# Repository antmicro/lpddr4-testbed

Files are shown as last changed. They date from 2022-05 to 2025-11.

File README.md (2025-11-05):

LPDDR4 testbed
==============

Copyright (c) 2020-2025 [Antmicro](https://www.antmicro.com)



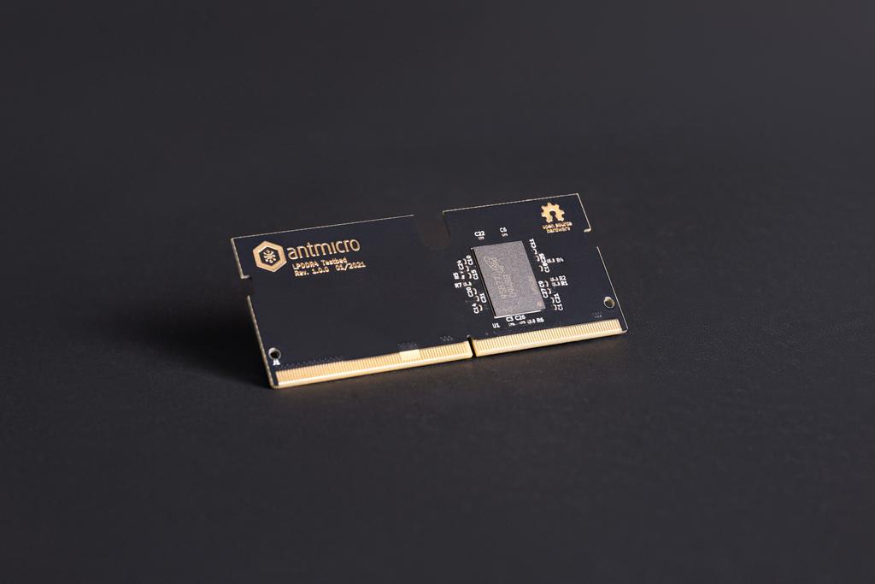
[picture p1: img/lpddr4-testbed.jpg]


Overview
--------

This repository contains open hardware design files for an experimental
test module in a form of SO-DIMM DDR4 module. The module includes a
standard 200-ball WFBGA (10mm × 14.5mm × 0.8mm, Ø0.35 SMD) LPDDR4 RAM
footprint break-routed in the SO-DOMM edge connector. The design files
were prepared in KiCad. Please note that this board is not electrically
compatible with off-the-shelf SO-DIMM DDR4 memory modules. It is
compatible with [this](https://github.com/antmicro/lpddr4-test-board)
LPDDR4 test platform.

Repository structure
--------------------

The main repository directory contains KiCad PCB project files, a
LICENSE and README. The remaining files are stored in the following
directories:

* `img` - contains graphics for this README

### Licensing

This project is published under the [Apache-2.0](LICENSE) license.

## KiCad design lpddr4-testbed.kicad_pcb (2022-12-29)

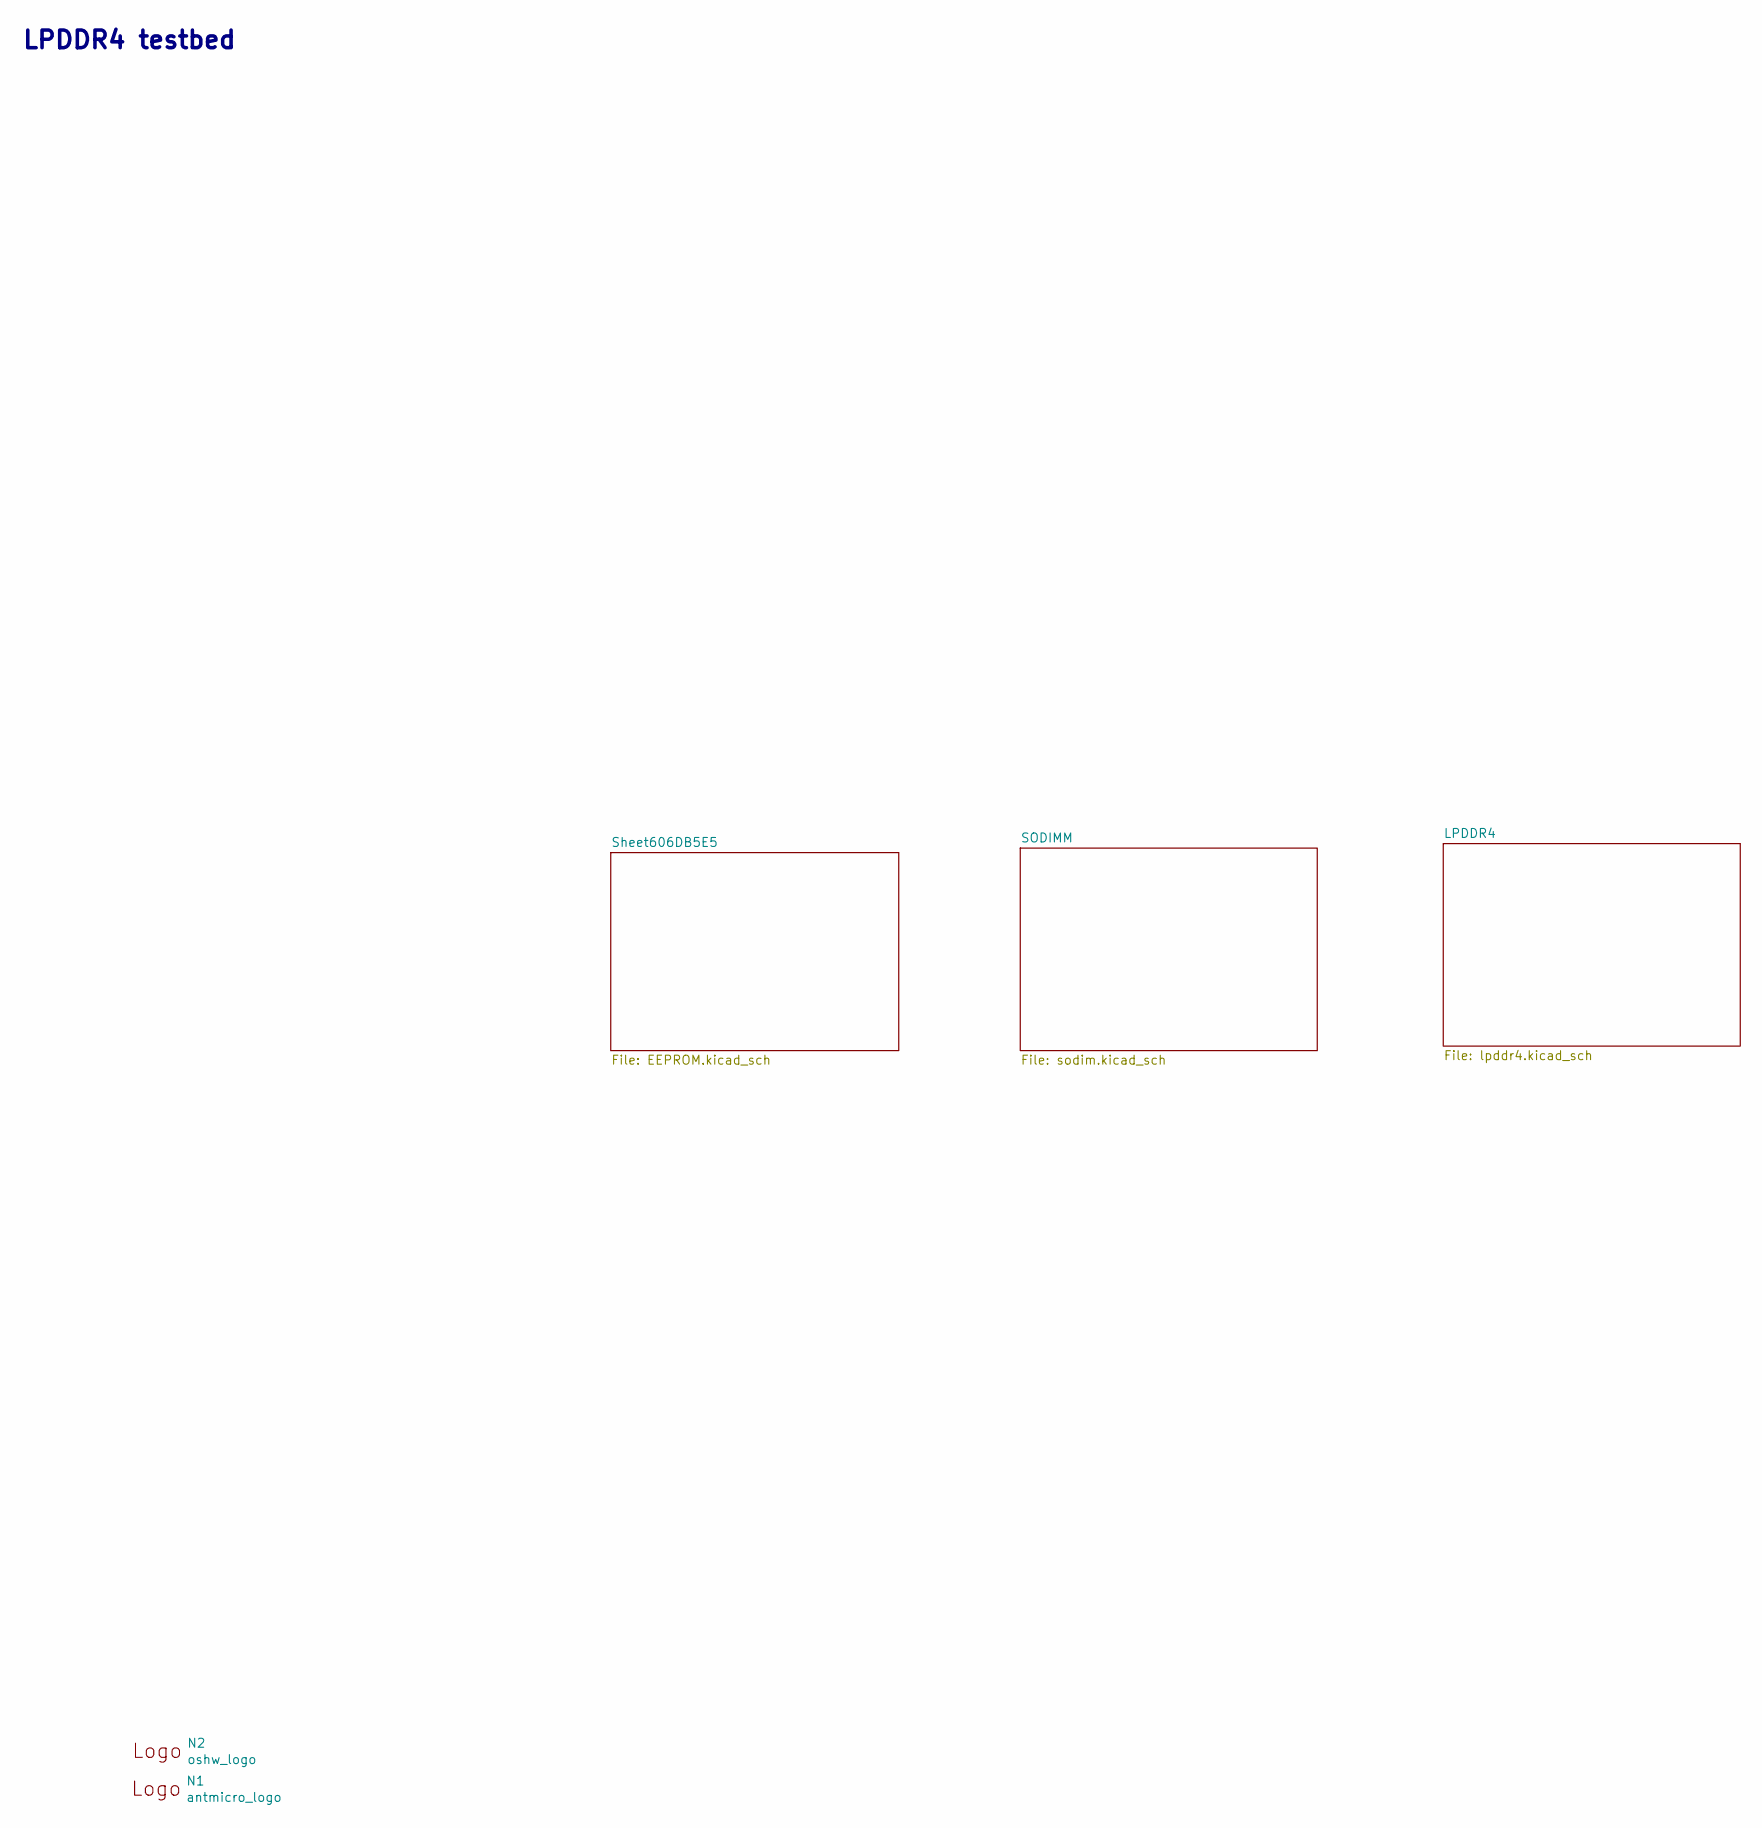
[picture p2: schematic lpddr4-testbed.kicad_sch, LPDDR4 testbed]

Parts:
N1: antmicro_logo; antmicro-logo_scaled_20mm
N2: oshw_logo; oshw-logo

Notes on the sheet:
LPDDR4 testbed

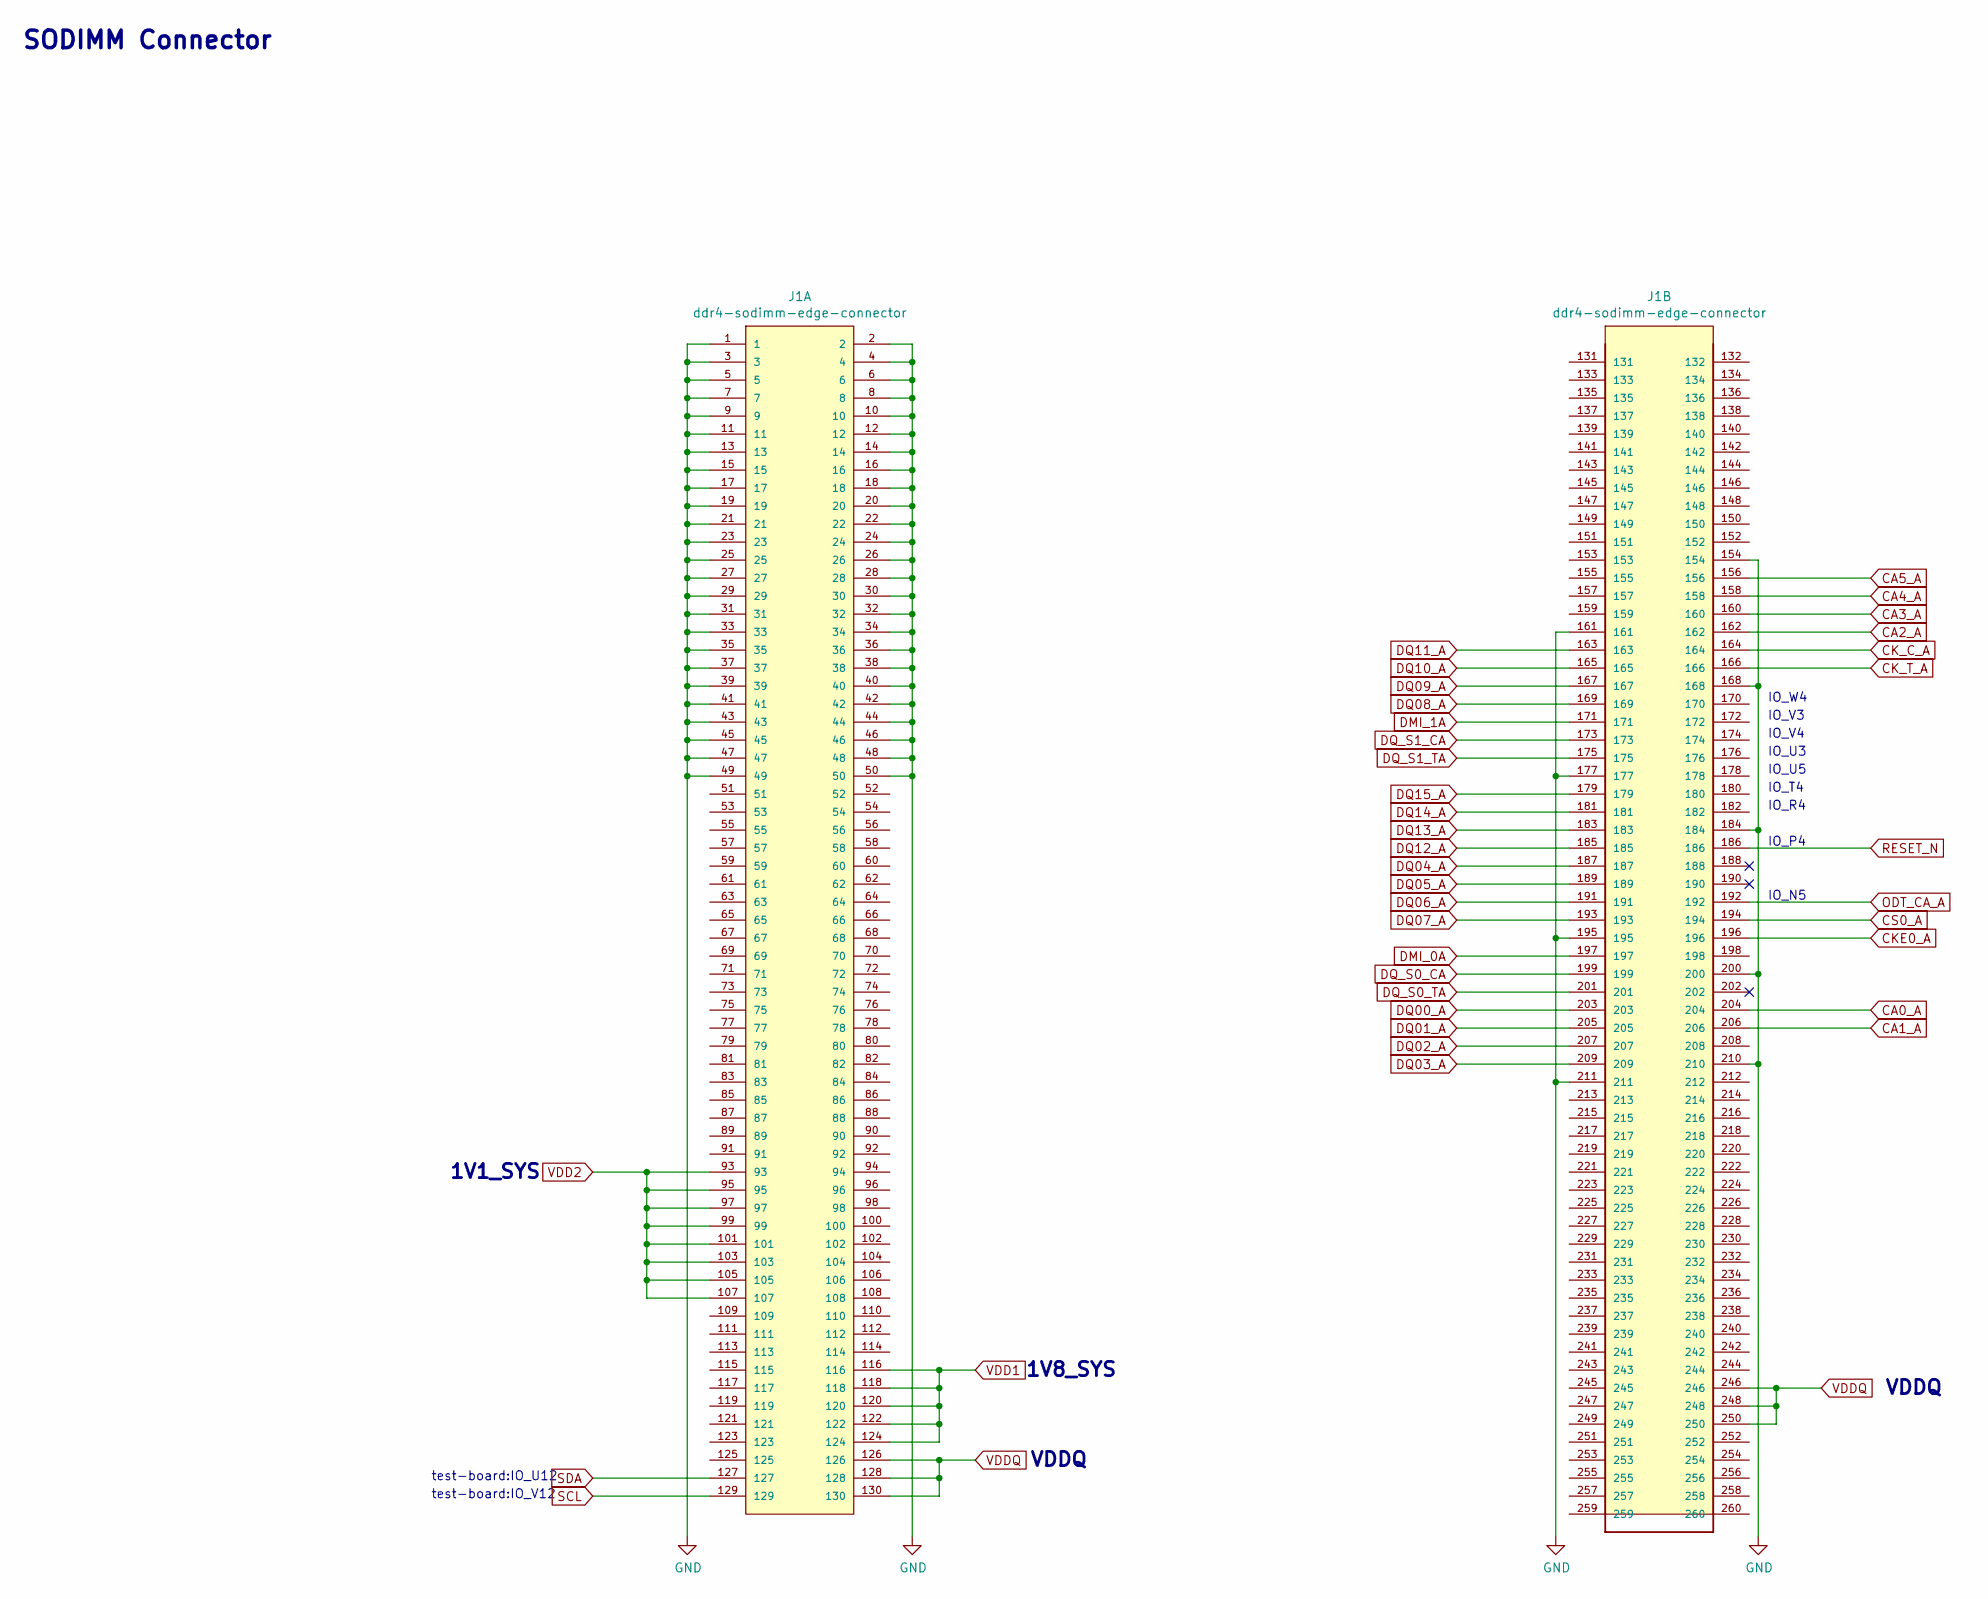
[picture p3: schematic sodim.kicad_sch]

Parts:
J1: ddr4-sodimm-edge-connector; SODIMM_DDR4_EDGE

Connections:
CA0_A: J1.204; also elsewhere on the board
CA1_A: J1.206; also elsewhere on the board
CA2_A: J1.162; also elsewhere on the board
CA3_A: J1.160; also elsewhere on the board
CA4_A: J1.158; also elsewhere on the board
CA5_A: J1.156; also elsewhere on the board
CKE0_A: J1.196; also elsewhere on the board
CK_C_A: J1.164; also elsewhere on the board
CK_T_A: J1.166; also elsewhere on the board
CS0_A: J1.194; also elsewhere on the board
DMI_0A: J1.197; also elsewhere on the board
DMI_1A: J1.171; also elsewhere on the board
DQ00_A: J1.203; also elsewhere on the board
DQ01_A: J1.205; also elsewhere on the board
DQ02_A: J1.207; also elsewhere on the board
DQ03_A: J1.209; also elsewhere on the board
DQ04_A: J1.187; also elsewhere on the board
DQ05_A: J1.189; also elsewhere on the board
DQ06_A: J1.191; also elsewhere on the board
DQ07_A: J1.193; also elsewhere on the board
DQ08_A: J1.169; also elsewhere on the board
DQ09_A: J1.167; also elsewhere on the board
DQ10_A: J1.165; also elsewhere on the board
DQ11_A: J1.163; also elsewhere on the board
DQ12_A: J1.185; also elsewhere on the board
DQ13_A: J1.183; also elsewhere on the board
DQ14_A: J1.181; also elsewhere on the board
DQ15_A: J1.179; also elsewhere on the board
DQ_S0_CA: J1.199; also elsewhere on the board
DQ_S0_TA: J1.201; also elsewhere on the board
DQ_S1_CA: J1.173; also elsewhere on the board
DQ_S1_TA: J1.175; also elsewhere on the board
GND: J1.1, J1.2, J1.3, J1.4, J1.5, J1.6, J1.7, J1.8, J1.9, J1.10, J1.11, J1.12, J1.13, J1.14, J1.15, J1.16, J1.17, J1.18, J1.19, J1.20, J1.21, J1.22, J1.23, J1.24, J1.25, J1.26, J1.27, J1.28, J1.29, J1.30, J1.31, J1.32, J1.33, J1.34, J1.35, J1.36, J1.37, J1.38, J1.39, J1.40, J1.41, J1.42, J1.43, J1.44, J1.45, J1.46, J1.47, J1.48, J1.49, J1.50, J1.154, J1.161, J1.168, J1.177, J1.184, J1.195, J1.200, J1.210, J1.211; also elsewhere on the board
ODT_CA_A: J1.192; also elsewhere on the board
RESET_N: J1.186; also elsewhere on the board
SCL: J1.129; also elsewhere on the board
SDA: J1.127; also elsewhere on the board
VDD1: J1.116, J1.118, J1.120, J1.122, J1.124; also elsewhere on the board
VDD2: J1.93, J1.95, J1.97, J1.99, J1.101, J1.103, J1.105, J1.107; also elsewhere on the board
VDDQ: J1.126, J1.128, J1.130, J1.246, J1.248, J1.250; also elsewhere on the board

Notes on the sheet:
IO_W4
IO_N5
IO_U5
IO_T4
test-board:IO_U12
VDDQ
IO_U3
IO_V4
IO_P4
test-board:IO_V12
SODIMM Connector
IO_V3
IO_R4
1V8_SYS
1V1_SYS

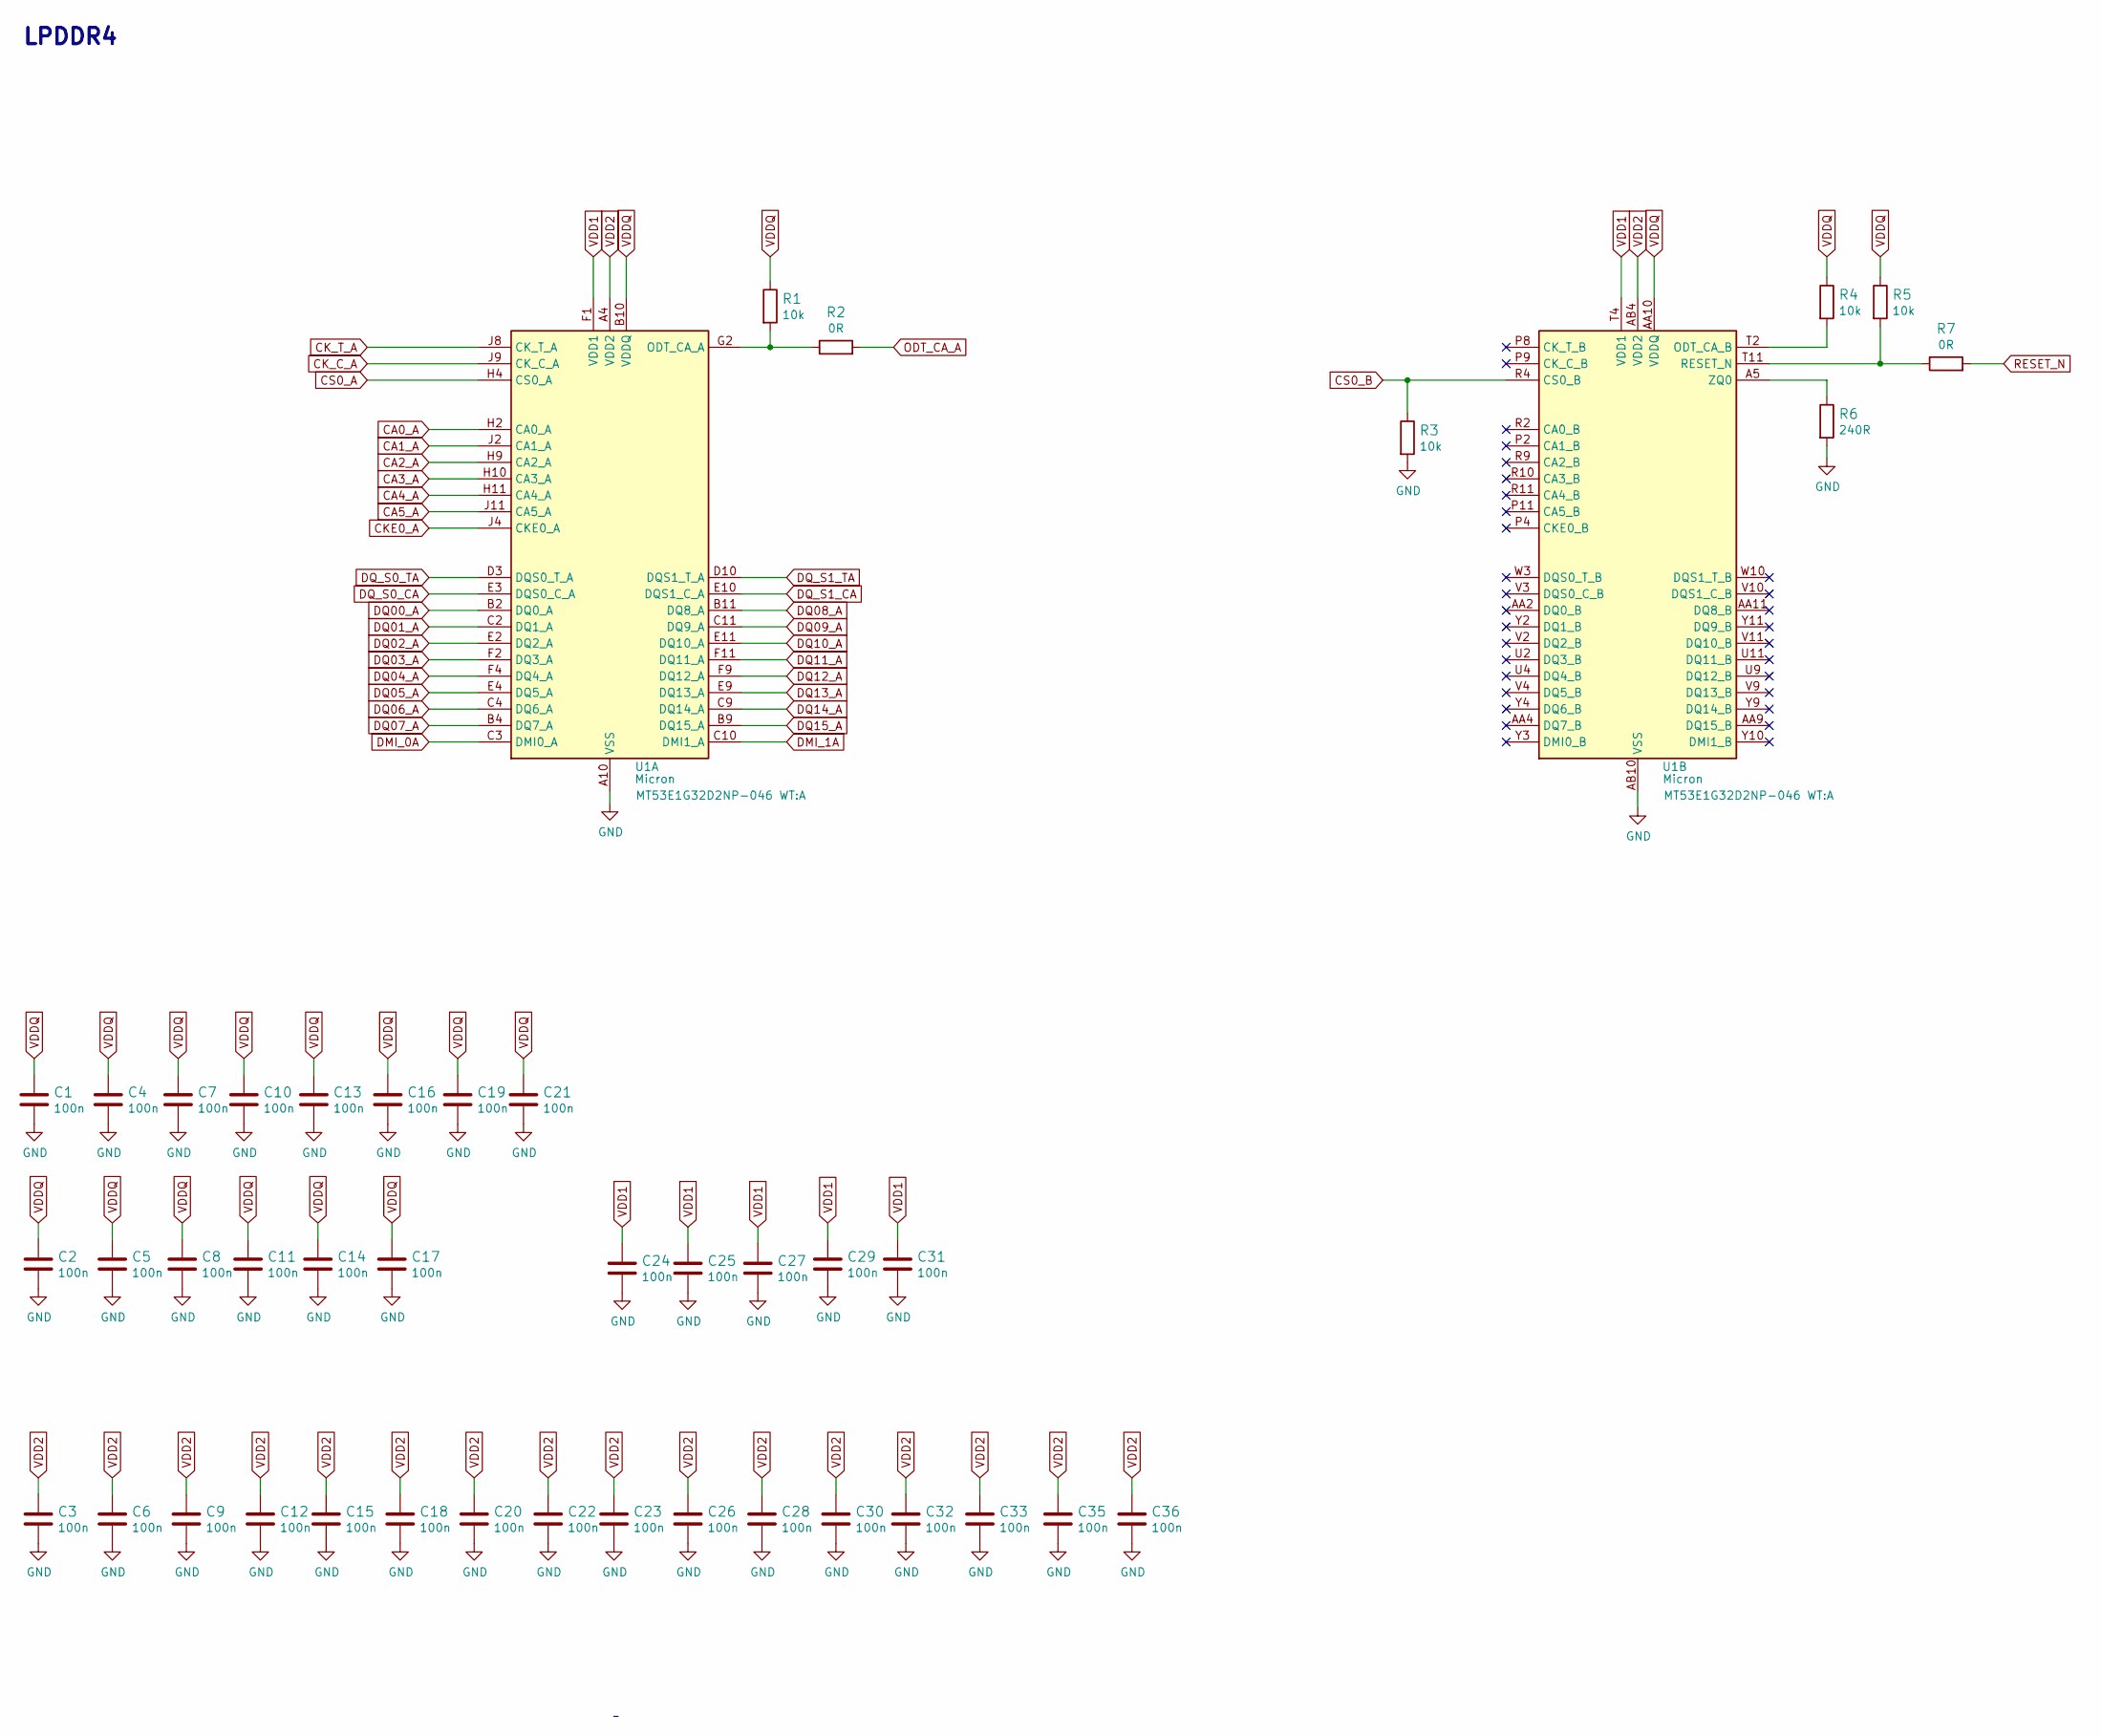
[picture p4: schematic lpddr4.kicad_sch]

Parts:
C1, C2, C3, C4, C5, C6, C7, C8, C9, C10, C11, C12, C13, C14, C15, C16, C17, C18, C19, C20, C21, C22, C23, C24, C25, C26, C27, C28, C29, C30, C31, C32, C33, C35, C36: C_100n_0201; 0201-res; MPN CC0201KRX6S5BB104
R1, R3, R4, R5: R_10k_0402; 0402-res; MPN CRCW040210K0FKEDHP
R2, R7: R_0R_0402; 0402-res; MPN ERJ2GE0R00X
R6: R_240R_0402; 0402-res; MPN ERJ2GEJ241X
U1: MT53E1G32D2NP-046; BGA-200_10.0x14.5mm_Layout12x22_P0.80x0.65mm; MPN MT53E1G32D2NP-046 WT:A

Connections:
CA0_A: U1.H2 (CA0_A); also elsewhere on the board
CA1_A: U1.J2 (CA1_A); also elsewhere on the board
CA2_A: U1.H9 (CA2_A); also elsewhere on the board
CA3_A: U1.H10 (CA3_A); also elsewhere on the board
CA4_A: U1.H11 (CA4_A); also elsewhere on the board
CA5_A: U1.J11 (CA5_A); also elsewhere on the board
CKE0_A: U1.J4 (CKE0_A); also elsewhere on the board
CK_C_A: U1.J9 (CK_C_A); also elsewhere on the board
CK_T_A: U1.J8 (CK_T_A); also elsewhere on the board
CS0_A: U1.H4 (CS0_A); also elsewhere on the board
CS0_B: R3.1, U1.R4 (CS0_B)
DMI_0A: U1.C3 (DMI0_A); also elsewhere on the board
DMI_1A: U1.C10 (DMI1_A); also elsewhere on the board
DQ00_A: U1.B2 (DQ0_A); also elsewhere on the board
DQ01_A: U1.C2 (DQ1_A); also elsewhere on the board
DQ02_A: U1.E2 (DQ2_A); also elsewhere on the board
DQ03_A: U1.F2 (DQ3_A); also elsewhere on the board
DQ04_A: U1.F4 (DQ4_A); also elsewhere on the board
DQ05_A: U1.E4 (DQ5_A); also elsewhere on the board
DQ06_A: U1.C4 (DQ6_A); also elsewhere on the board
DQ07_A: U1.B4 (DQ7_A); also elsewhere on the board
DQ08_A: U1.B11 (DQ8_A); also elsewhere on the board
DQ09_A: U1.C11 (DQ9_A); also elsewhere on the board
DQ10_A: U1.E11 (DQ10_A); also elsewhere on the board
DQ11_A: U1.F11 (DQ11_A); also elsewhere on the board
DQ12_A: U1.F9 (DQ12_A); also elsewhere on the board
DQ13_A: U1.E9 (DQ13_A); also elsewhere on the board
DQ14_A: U1.C9 (DQ14_A); also elsewhere on the board
DQ15_A: U1.B9 (DQ15_A); also elsewhere on the board
DQ_S0_CA: U1.E3 (DQS0_C_A); also elsewhere on the board
DQ_S0_TA: U1.D3 (DQS0_T_A); also elsewhere on the board
DQ_S1_CA: U1.E10 (DQS1_C_A); also elsewhere on the board
DQ_S1_TA: U1.D10 (DQS1_T_A); also elsewhere on the board
GND: C1.2, C2.2, C3.2, C4.2, C5.2, C6.2, C7.2, C8.2, C9.2, C10.2, C11.2, C12.2, C13.2, C14.2, C15.2, C16.2, C17.2, C18.2, C19.2, C20.2, C21.2, C22.2, C23.2, C24.2, C25.2, C26.2, C27.2, C28.2, C29.2, C30.2, C31.2, C32.2, C33.2, C35.2, C36.2, R3.2, R6.2, U1.A3 (VSS), U1.A10 (VSS), U1.AB3 (VSS), U1.AB5 (VSS), U1.AB8 (VSS), U1.AB10 (VSS), U1.C1 (VSS), U1.C5 (VSS), U1.C8 (VSS), U1.C12 (VSS), U1.D2 (VSS), U1.D4 (VSS), U1.D9 (VSS), U1.D11 (VSS), U1.E1 (VSS), U1.E5 (VSS), U1.E8 (VSS), U1.E12 (VSS), U1.G1 (VSS), U1.G3 (VSS), U1.G5 (VSS), U1.G8 (VSS), U1.G10 (VSS), U1.G12 (VSS), U1.J1 (VSS), U1.J3 (VSS), U1.J10 (VSS), U1.J12 (VSS), U1.K2 (VSS), U1.K4 (VSS), U1.K9 (VSS), U1.K11 (VSS), U1.N2 (VSS), U1.N4 (VSS), U1.N9 (VSS), U1.N11 (VSS), U1.P1 (VSS), U1.P3 (VSS), U1.P10 (VSS), U1.P12 (VSS), U1.T1 (VSS), U1.T3 (VSS), U1.T5 (VSS), U1.T8 (VSS), U1.T10 (VSS), U1.T12 (VSS), U1.V1 (VSS), U1.V5 (VSS), U1.V8 (VSS), U1.V12 (VSS), U1.W2 (VSS), U1.W4 (VSS), U1.W9 (VSS), U1.W11 (VSS), U1.Y1 (VSS), U1.Y5 (VSS), U1.Y8 (VSS), U1.Y12 (VSS); also elsewhere on the board
unnamed: R1.2, R2.1, U1.G2 (ODT_CA_A)
unnamed: R4.2, U1.T2 (ODT_CA_B)
unnamed: R5.2, R7.1, U1.T11 (RESET_N)
unnamed: R6.1, U1.A5 (ZQ0)
ODT_CA_A: R2.2; also elsewhere on the board
RESET_N: R7.2; also elsewhere on the board
VDD1: C24.1, C25.1, C27.1, C29.1, C31.1, U1.F1 (VDD1), U1.F12 (VDD1), U1.G4 (VDD1), U1.G9 (VDD1), U1.T4 (VDD1), U1.T9 (VDD1), U1.U1 (VDD1), U1.U12 (VDD1); also elsewhere on the board
VDD2: C3.1, C6.1, C9.1, C12.1, C15.1, C18.1, C20.1, C22.1, C23.1, C26.1, C28.1, C30.1, C32.1, C33.1, C35.1, C36.1, U1.A4 (VDD2), U1.A9 (VDD2), U1.AB4 (VDD2), U1.AB9 (VDD2), U1.F5 (VDD2), U1.F8 (VDD2), U1.H1 (VDD2), U1.H5 (VDD2), U1.H8 (VDD2), U1.H12 (VDD2), U1.K1 (VDD2), U1.K3 (VDD2), U1.K10 (VDD2), U1.K12 (VDD2), U1.N1 (VDD2), U1.N3 (VDD2), U1.N10 (VDD2), U1.N12 (VDD2), U1.R1 (VDD2), U1.R5 (VDD2), U1.R8 (VDD2), U1.R12 (VDD2), U1.U5 (VDD2), U1.U8 (VDD2); also elsewhere on the board
VDDQ: C1.1, C2.1, C4.1, C5.1, C7.1, C8.1, C10.1, C11.1, C13.1, C14.1, C16.1, C17.1, C19.1, C21.1, R1.1, R4.1, R5.1, U1.AA3 (VDDQ), U1.AA5 (VDDQ), U1.AA8 (VDDQ), U1.AA10 (VDDQ), U1.B3 (VDDQ), U1.B5 (VDDQ), U1.B8 (VDDQ), U1.B10 (VDDQ), U1.D1 (VDDQ), U1.D5 (VDDQ), U1.D8 (VDDQ), U1.D12 (VDDQ), U1.F3 (VDDQ), U1.F10 (VDDQ), U1.U3 (VDDQ), U1.U10 (VDDQ), U1.W1 (VDDQ), U1.W5 (VDDQ), U1.W8 (VDDQ), U1.W12 (VDDQ); also elsewhere on the board

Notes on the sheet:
LPDDR4

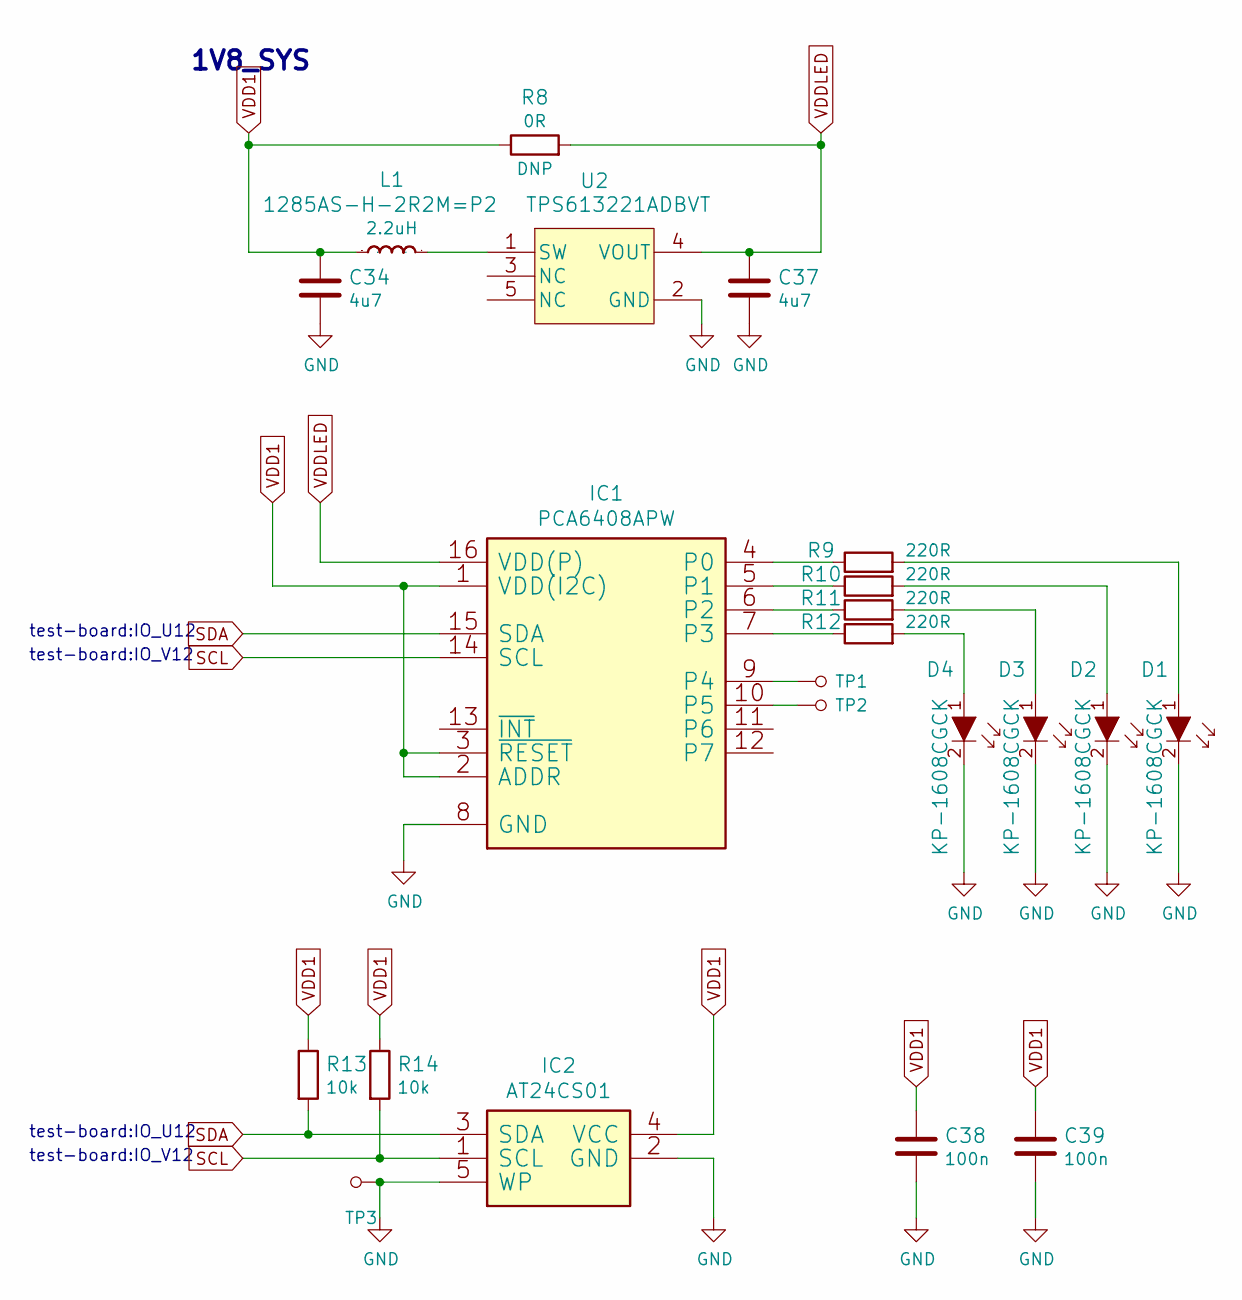
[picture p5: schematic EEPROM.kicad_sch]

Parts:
C34, C37: C_4u7_0402; 0402-cap; MPN GRM155R61A475MEAAD
C38, C39: C_100n_0402; 0402-cap; MPN 0402X104K6R3CT
D1, D2, D3, D4: KP-1608CGCK; LED_0603; MPN KP-1608CGCK
IC1: PCA6408APW; TSSOP-16; MPN PCA6408APW
IC2: AT24CS01; SOT-23-5; MPN AT24CS01-ST
L1: 1285AS-H-2R2M=P2; 0805-res; MPN 1285AS-H-2R2M=P2
R8: R_0R_0402; 0402-res; MPN ERJ2GE0R00X
R9, R10, R11, R12: R_220R_0402; 0402-res; MPN ERJ2GEJ221X
R13, R14: R_10k_0402; 0402-res; MPN CRCW040210K0FKEDHP
TP1, TP2, TP3: TP_SMD1MM; Testpoint_smd_1mm
U2: TPS613221ADBVT; SOT-23-5; MPN TPS613221ADBVT

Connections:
GND: C34.2, C37.2, C38.2, C39.2, D1.2, D2.2, D3.2, D4.2, IC1.8 (GND), IC2.2 (GND), IC2.5 (WP), TP3.1, U2.2 (GND); also elsewhere on the board
unnamed: D1.1, R9.2
unnamed: D2.1, R10.2
unnamed: D3.1, R11.2
unnamed: D4.1, R12.2
unnamed: IC1.4 (P0), R9.1
unnamed: IC1.5 (P1), R10.1
unnamed: IC1.6 (P2), R11.1
unnamed: IC1.7 (P3), R12.1
unnamed: IC1.9 (P4), TP1.1
unnamed: IC1.10 (P5), TP2.1
unnamed: L1.2, U2.1 (SW)
SCL: IC1.14 (SCL), IC2.1 (SCL), R14.2; also elsewhere on the board
SDA: IC1.15 (SDA), IC2.3 (SDA), R13.2; also elsewhere on the board
VDD1: C34.1, C38.1, C39.1, IC1.1 (VDD(I2C)), IC1.2 (ADDR), IC1.3 (~RESET), IC2.4 (VCC), L1.1, R8.1, R13.1, R14.1; also elsewhere on the board
VDDLED: C37.1, IC1.16 (VDD(P)), R8.2, U2.4 (VOUT)

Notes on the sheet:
test-board:IO_V12
test-board:IO_U12
1V8_SYS

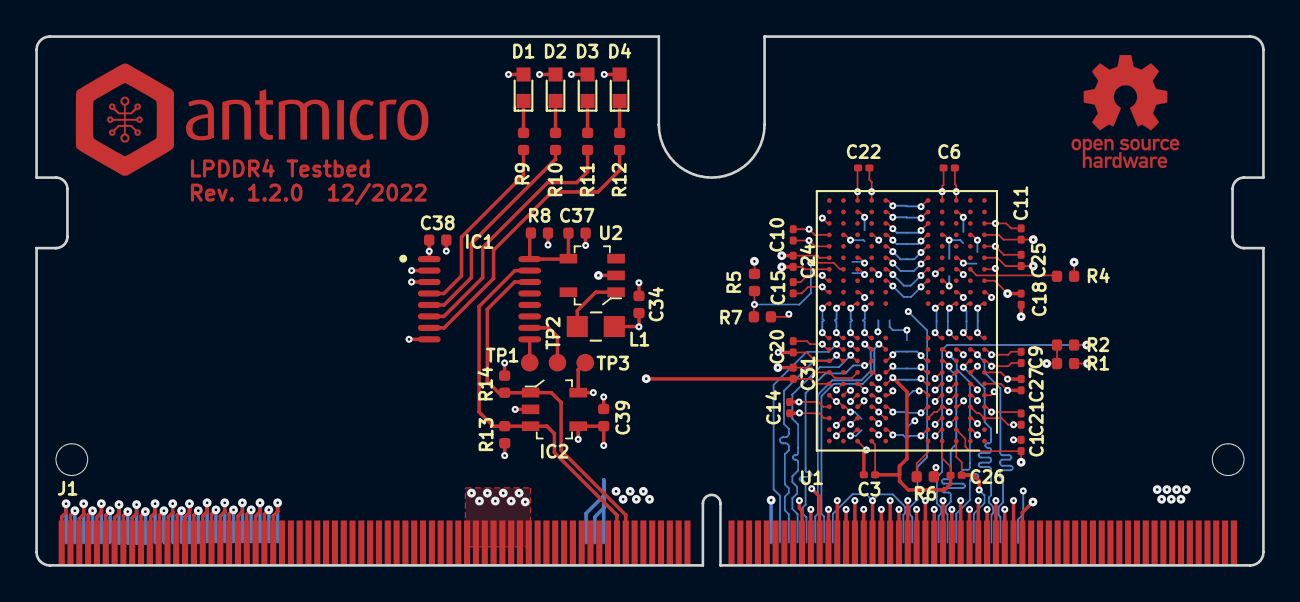
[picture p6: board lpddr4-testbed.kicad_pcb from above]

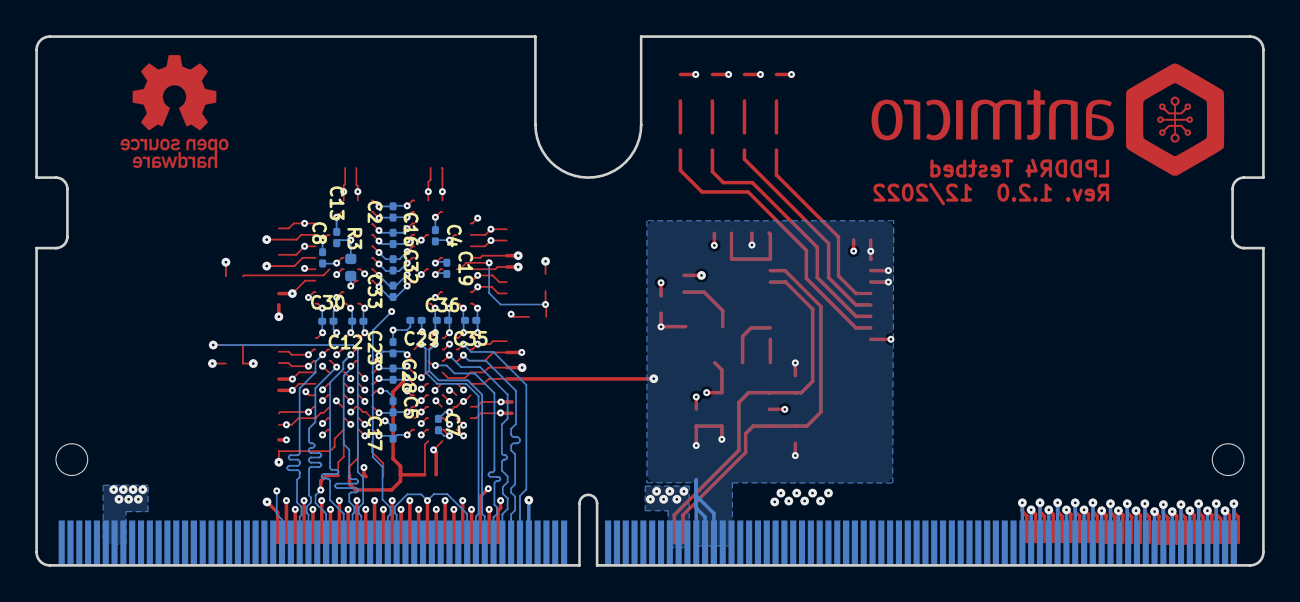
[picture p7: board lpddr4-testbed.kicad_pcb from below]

Board: 6 copper layers, 69.6 x 30.0 mm, 68 parts (19 on the bottom side), 57 nets.

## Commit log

2020-11-02 Add schamatic sheet
    [ddr-testbed.sch]
2020-12-10 Add basic PCB outline
    [ddr-testbed.kicad_pcb]
2020-12-10 Fix outline
    [ddr-testbed.kicad_pcb]
2020-12-10 Add double die configuration
    [ddr-testbed.sch]
2020-12-10 Add data resistors sheet
    [data_resistors.sch, ddr-testbed.sch]
2020-12-10 Fix outline_v2
    [ddr-testbed.kicad_pcb]
2020-12-10 Add power filtering sheet
    [ddr-testbed.sch, power_filtering.sch]
2020-12-10 Change labels to global
    [data_resistors.sch, ddr-testbed.sch]
2020-12-10 Add changes refering to Xilinx documentation
    [ddr-testbed.sch]
2020-12-10 Add changes in pull ups and add missing components
    [ddr-testbed.sch]
2020-12-10 Add changes around CKE pins and some notes
    [ddr-testbed.sch]
2020-12-10 Remove data resistors sheet and add notes
    [data_resistors.sch, ddr-testbed.sch, power_filtering.sch]
2020-12-10 Add initial component placement
    [ddr-testbed.kicad_pcb]
2020-12-10 Add LPDDR4 Fanout and pinout tabele
    [ddr-testbed.kicad_pcb]
2020-12-10 Redesign power supply and filtering WIP
    [ddr-testbed.sch, power_filtering.sch]
2020-12-10 Replace capacitors and place them on PCB
    [ddr-testbed.kicad_pcb, ddr-testbed.sch]
2020-12-10 Preliminary LPDDR4 escape layout
    [ddr-testbed.kicad_pcb, ddr-testbed.sch]
2020-12-10 LPDDR4 escape done, replaced DDR3 edge connector (requires connecting)
    [ddr-testbed.kicad_pcb, ddr-testbed.sch]
2020-12-10 Updated LPDDR4 connection on edge connector (supplies to be added)
    [ddr-testbed.kicad_pcb, ddr-testbed.sch]
2020-12-10 Passive components update, edge connector routing wip
    [ddr-testbed.kicad_pcb, ddr-testbed.sch]
2020-12-10 Added edge connector escape
    [ddr-testbed.kicad_pcb]
2020-12-10 Routing of all high speed DDR signals done
    [ddr-testbed.kicad_pcb, ddr-testbed.sch]
2020-12-10 Connect power supply to SO-DIMM connector
    [ddr-testbed.sch]
2020-12-10 Update file structure
    [ddr-testbed.kicad_pcb, ddr-testbed.sch, lpddr4-testbed.kicad_pcb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]
2020-12-10 Temporarily move filtering caps
    [lpddr4-testbed.kicad_pcb]
2020-12-10 Introduce schematic sheets
    [filtering.sch, lpddr4-testbed.sch, lpddr4.sch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]
2020-12-10 Update edge connector
    [lpddr4-testbed.kicad_pcb, sodim.sch]
2020-12-10 Connect power supplies and CHANNEL A signals to edge connector
    [lpddr4-testbed.kicad_pcb, lpddr4.sch, sodim.sch]
2020-12-10 Connect signals to DDR CHANNEL A
    [lpddr4.sch]
2020-12-10 Update board setup for 6L
    [lpddr4-testbed.kicad_pcb]
2020-12-10 Reverse connections of DQ4_A ... DQ0_A
    [lpddr4-testbed.kicad_pcb, sodim.sch]
2020-12-10 Connect CA and DQ signals
    [lpddr4-testbed.kicad_pcb]
2020-12-10 Add tune DQ length
    [lpddr4-testbed.kicad_pcb]
2020-12-10 Equalize CA lanes
    [lpddr4-testbed.kicad_pcb]
2020-12-10 Add vias for power distribution
    [lpddr4-testbed.kicad_pcb]
2020-12-13 Remove obsolete RC components around CK and CE signals
    [lpddr4.sch]
2020-12-13 Cleanup, add TODOs
    [lpddr4.sch]
2020-12-14 Add filtering caps to VDDQ
    [lpddr4-testbed.kicad_pcb, lpddr4.sch, sodimm.sch]
2020-12-14 Add Filtering to VCC1
    [lpddr4-testbed.kicad_pcb, lpddr4.sch]
2020-12-14 Add filtering to VDD1
    [lpddr4-testbed.kicad_pcb, lpddr4.sch]
2020-12-14 Route power planes
    [lpddr4-testbed.kicad_pcb]
2020-12-14 Fully routed, DRC clean
    [lpddr4-testbed.kicad_pcb, lpddr4-testbed.sch, lpddr4.sch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]
2021-01-13 Reconnect RESET_N and ODT_CA to IO_P4 and IO_N5
    [lpddr4-testbed.kicad_pcb, sodim.sch]
2021-01-13 Remove note
    [lpddr4.sch]
2021-01-13 Update references
    [lpddr4-testbed.kicad_pcb]
2021-01-13 Add OSHW logotype
    [lpddr4-testbed.kicad_pcb, lpddr4.sch]
2021-01-13 Optimize pairs of buried vias
    [lpddr4-testbed.kicad_pcb, lpddr4-testbed.sch, lpddr4.sch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]
2021-01-13 Update local libs, resolve DRC
    [lpddr4-testbed.kicad_pcb, lpddr4-testbed.sch, lpddr4.sch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]
2021-01-13 Remove redundant sheet
    [filtering.sch]
2021-04-01 Update DRAM MPN
    [lpddr4-testbed-BOM-by-layer.csv, lpddr4-testbed-BOM-populated.csv, lpddr4-testbed.kicad_pcb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]
2021-04-02 Added sheet for EEPROM/LEDs
    [EEPROM.sch, lpddr4-testbed.sch, lpddr4.sch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]
2021-04-07 Added EEPROM and LED circuits to schematic
    [EEPROM.sch]
2021-04-07 Component placement for EEPROM/LEDs
    [EEPROM.sch, lpddr4-testbed.kicad_pcb]
2021-04-22 Changed DDR type to MT53E1G32D2NP-046 WT:A
    [lpddr4-testbed.kicad_pcb, lpddr4.sch]
2021-04-22 Add eeprom routing
    [lpddr4-testbed.kicad_pcb]
2021-04-22 Update schematics
2021-05-06 Bump revision to 1.1.0
    [EEPROM.sch, lpddr4-testbed.sch, lpddr4.sch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]
2021-05-20 Bumped rev on PCB
    [lpddr4-testbed.kicad_pcb]
2021-07-02 Replace broken component -PCA6408APW
    [EEPROM.sch, lpddr4-testbed.kicad_pcb, lpddr4.sch]
2022-12-28 Migrate to KiCad 6
    [EEPROM.kicad_sch, EEPROM.sch, lpddr4-testbed.kicad_pcb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]
2022-12-28 Clean DRC
    [lpddr4-testbed.kicad_pcb]
2022-12-28 Replace burried vias with regular vias
    [lpddr4-testbed.kicad_pcb]
2022-12-29 Fix net names
    [EEPROM.kicad_sch, lpddr4-testbed.kicad_pcb, lpddr4-testbed.kicad_sch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]
2022-12-29 Length matching
    [lpddr4-testbed.kicad_pcb]
2022-12-29 Bump revision to 1.2.0
    [EEPROM.kicad_sch, lpddr4-testbed.kicad_pcb, lpddr4-testbed.kicad_sch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]
2022-12-30 Update signage
    [EEPROM.kicad_sch, lpddr4-testbed-BOM-by-layer.csv, lpddr4-testbed-BOM-populated.csv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]
2022-12-30 Update schematic
2023-05-30 [#45231] globlib
    [EEPROM.kicad_sch, lpddr4-testbed.kicad_sch, lpddr4.kicad_sch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]
2023-05-30 Fix missing global links (wip), designators fixed
    [EEPROM.kicad_sch, lpddr4-testbed.kicad_sch, lpddr4.kicad_sch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]
2023-05-31 Fix missing global links
    [EEPROM.kicad_sch, lpddr4-testbed.kicad_sch]
2023-10-13 Introduce component standardization
    [EEPROM.kicad_sch, lpddr4-testbed.kicad_sch, lpddr4.kicad_sch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]
2023-10-16 Add OHP assets, stop ignoring csv
    [stackup.csv]
2024-03-25 [#56947] Correct component references
    [EEPROM.kicad_sch, lpddr4-testbed.kicad_sch, lpddr4.kicad_sch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]
2024-03-26 [#56947] Fix missing highlights in OHP
    [lpddr4.kicad_sch]
2024-03-26 [#56947] Loclib
    [EEPROM.kicad_sch, lpddr4.kicad_sch, sodim.kicad_sch]
2024-03-26 [#56947] Bump revision & date
    [EEPROM.kicad_sch, lpddr4-testbed.kicad_sch, lpddr4.kicad_sch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]
2024-03-29 [#56947] Removed KiCAD 5 files
2025-11-05 [#86301] Project refresh 81589
    [EEPROM.kicad_sch, lpddr4-testbed.kicad_sch, lpddr4.kicad_sch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]
